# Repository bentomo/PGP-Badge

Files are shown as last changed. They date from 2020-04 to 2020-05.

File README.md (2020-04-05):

# Pokemon Go Plus Custom Badge

## Installing Toolchain

This was all tested under Windows 10

1. Install Python 2.7 (This is tested by 2.7.12)
	This is required for the edf-sdk installer

2. Install CMake for Windows (Tested using 3.17.0)

3. Install espressif SDK (Tested using Windows installer 2.2)
https://docs.espressif.com/projects/esp-idf/en/latest/get-started/#id1

I needed to use this because of an installer problem
https://github.com/espressif/esp-idf/issues/4744

`python.exe -m pip install --upgrade virtualenv==16.7.9`

Then run the program as administrator

## Extracting a MAC, Blob, and Key

Note that this is unusable without a Mac address, BLOB and device key from an **ORIGINAL** Pokemon GO plus
Pokeball plus and Gotcha not supported
https://github.com/Jesus805/Suota-Go-Plus

It's easiest to use the release page app 

Currently the app is bugged, it can download custom firmware but you need to use the  nRF android app to extract the values and restore the FW
MAC address is given by the app
characteristic `870d5ab1-20bd-b88a-5746-a97f5c33ea58` is the device key
characteristic `fe0002af-f8e3-f1b2-b141-b40adf381d18` is the blob

To restore the FW

1. Write 0x01 to Characteristic `6b64be6f-5467-d8b5-7143-1716be1b96be`
2. Disconnect from the device
3. Wait a few seconds
4. Press the Pokemon Go Plus button, it should be flashing blue or white

## Building the firmware

1. Open a command window
2. Browse to the esp-idf folder and run export.bat to setup sdk
3. Browse to the pgpemu-esp32 project folder and run `idf.py menuconfig`
4. Exit using the default configuration
5. Modify your secrets.c file with your MAC, Blob, and Key extracted from an original Pokemon GO Plus - This file is not tracked by git
6. Build the firmware using `idf.py build`
7. Flash the firmware using `idf.py -p (PORT) flash` where (PORT) is the COMX that the esp32 enumerated as

For more background read:
http://tinyhack.com/2018/11/21/reverse-engineering-pokemon-go-plus/

## Preliminary parts list
> ESP32 - Bluetooth - https://www.digikey.com/product-detail/en/espressif-systems/ESP32-WROOM-32/1904-1010-1-ND/8544305
> SSD1306 - OLED LCD - https://www.amazon.com/WINGONEER-Display-SSD1306-Headers-Arduino/dp/B07QB65CPS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
> ~~ adafruit 1578 - 500mah battery - https://www.digikey.com/product-detail/en/adafruit-industries-llc/1578/1528-1841-ND/5054539 ~~
> battery - https://www.digikey.com/product-detail/en/tinycircuits/ASR00008/1832-1044-ND/8680974
> BQ27426 - Fuel Gauge - https://www.digikey.com/product-detail/en/texas-instruments/BQ27426YZFR/296-43359-1-ND/5806500
> LM3658 - Battery Charger - https://www.digikey.com/product-detail/en/texas-instruments/LM3658SD-NOPB/LM3658SD-NOPBCT-ND/808013
> TPS63030 - Voltage Regulator - https://www.digikey.com/product-detail/en/texas-instruments/TPS63030DSKR/296-39460-1-ND/5143408
> CP2102N - USB Interface - https://www.digikey.com/product-detail/en/silicon-labs/CP2102N-A01-GQFN20R/336-4826-1-ND/8619802
> USB4085 - Through hole usb c - https://www.digikey.com/product-detail/en/gct/USB4085-GF-A/2073-USB4085-GF-ACT-ND/9859733
> 316040004 - Vibration Motor - https://www.digikey.com/product-detail/en/seeed-technology-co-ltd/316040004/1597-1245-ND/5487673
> ~~ BQ297X - Protection Circuit - http://www.ti.com/lit/ds/symlink/bq2971.pdf ~ Battery includes protection circuit~

Other components not listed
jelly beans
sense resitors
tactile switches
mechanicals

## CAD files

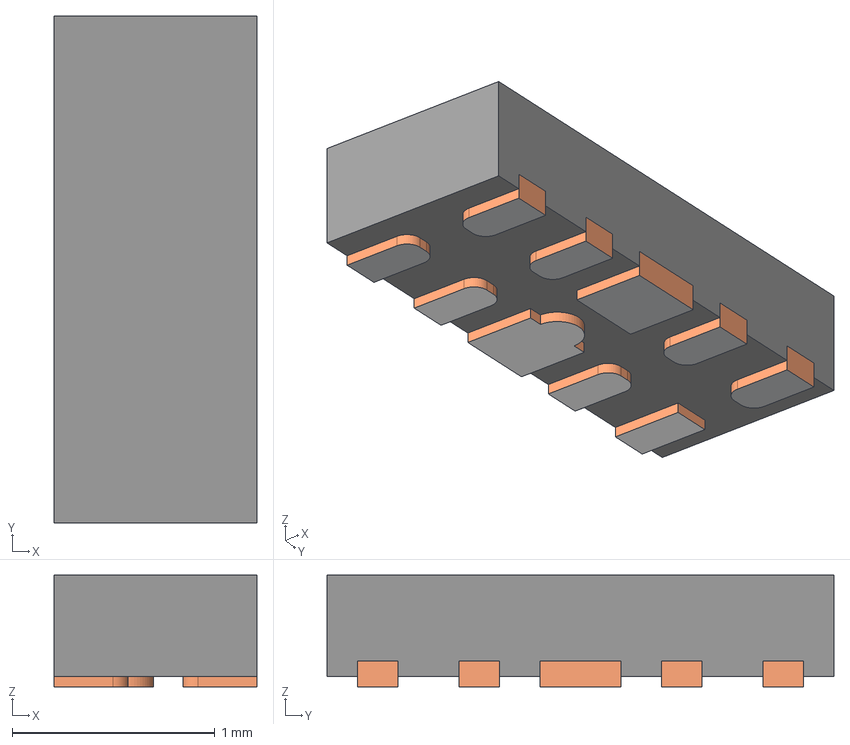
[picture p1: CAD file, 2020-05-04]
pcb/pgpbadge/3dModels/DQA0010A.stp
1.00 x 2.50 x 0.55 mm
BODY-SON
FRAME-DQA0010A
PIN1-ID

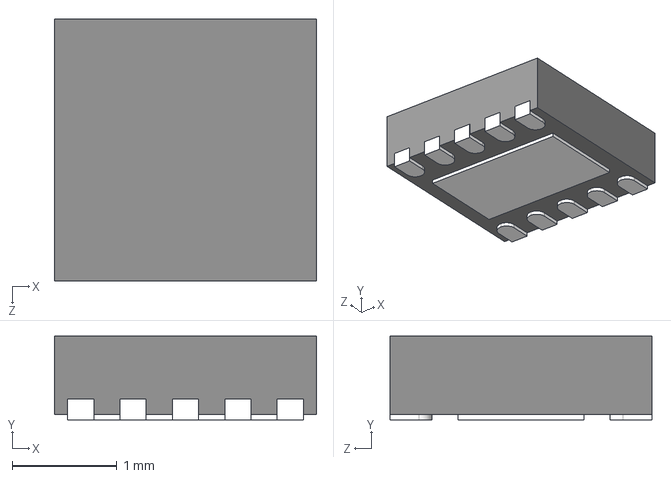
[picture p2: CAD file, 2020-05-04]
pcb/pgpbadge/3dModels/wson-10-ep-2_5_2_5.step
2.50 x 0.8 x 2.50 mm

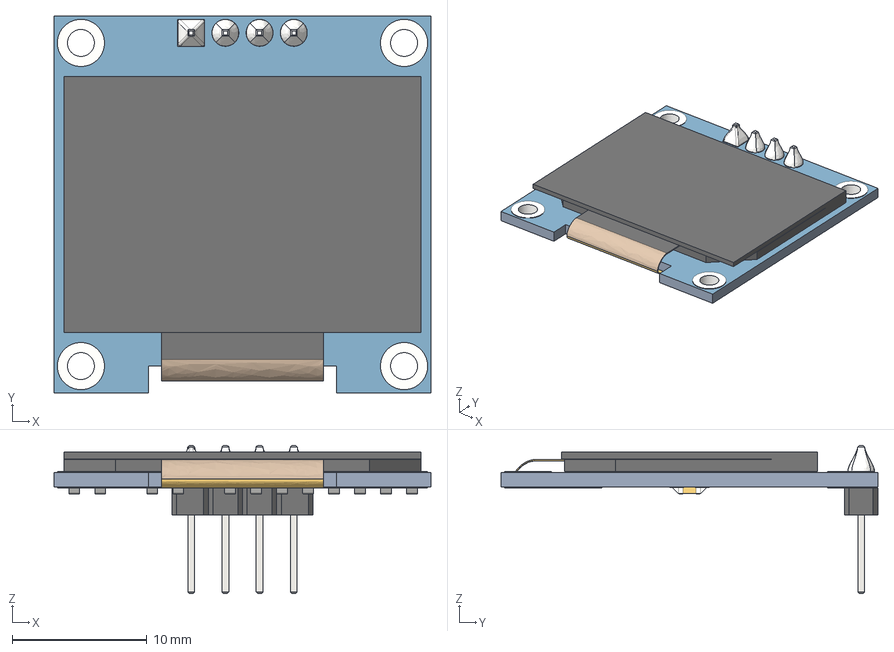
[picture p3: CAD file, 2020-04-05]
pcb/pgpbadge/3dModels/0_96_OLEDv3.step
28.0 x 28.0 x 11.0 mm

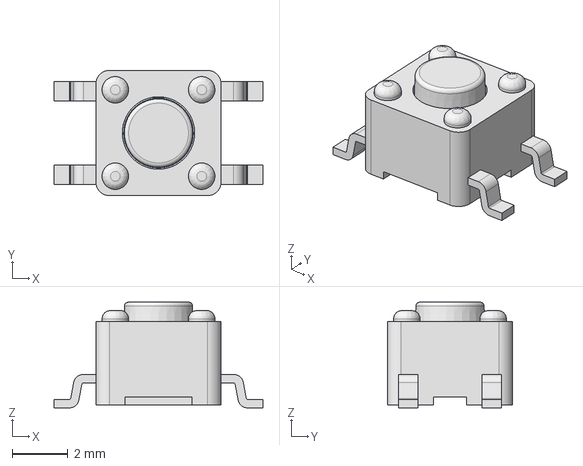
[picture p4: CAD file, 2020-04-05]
pcb/pgpbadge/3dModels/TL3305AFxxxxG.stp
7.50 x 4.50 x 3.80 mm

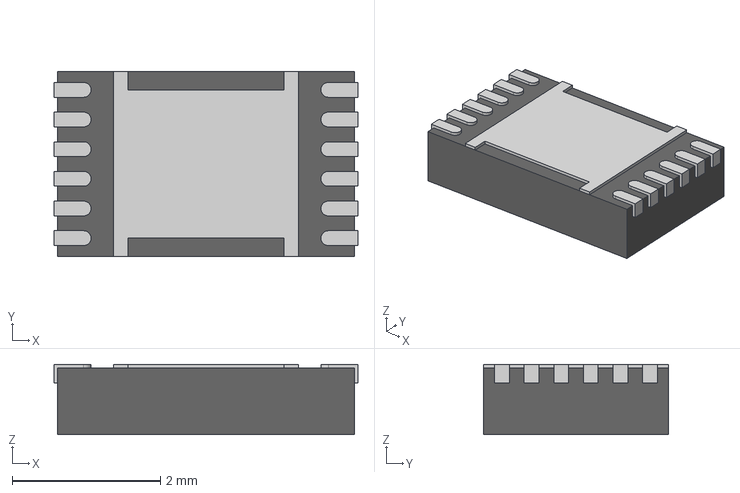
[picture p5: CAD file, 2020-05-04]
pcb/pgpbadge/3dModels/BQ27441DRZT-G1A--3DModel-STEP-191390.STEP
4.10 x 2.50 x 0.95 mm

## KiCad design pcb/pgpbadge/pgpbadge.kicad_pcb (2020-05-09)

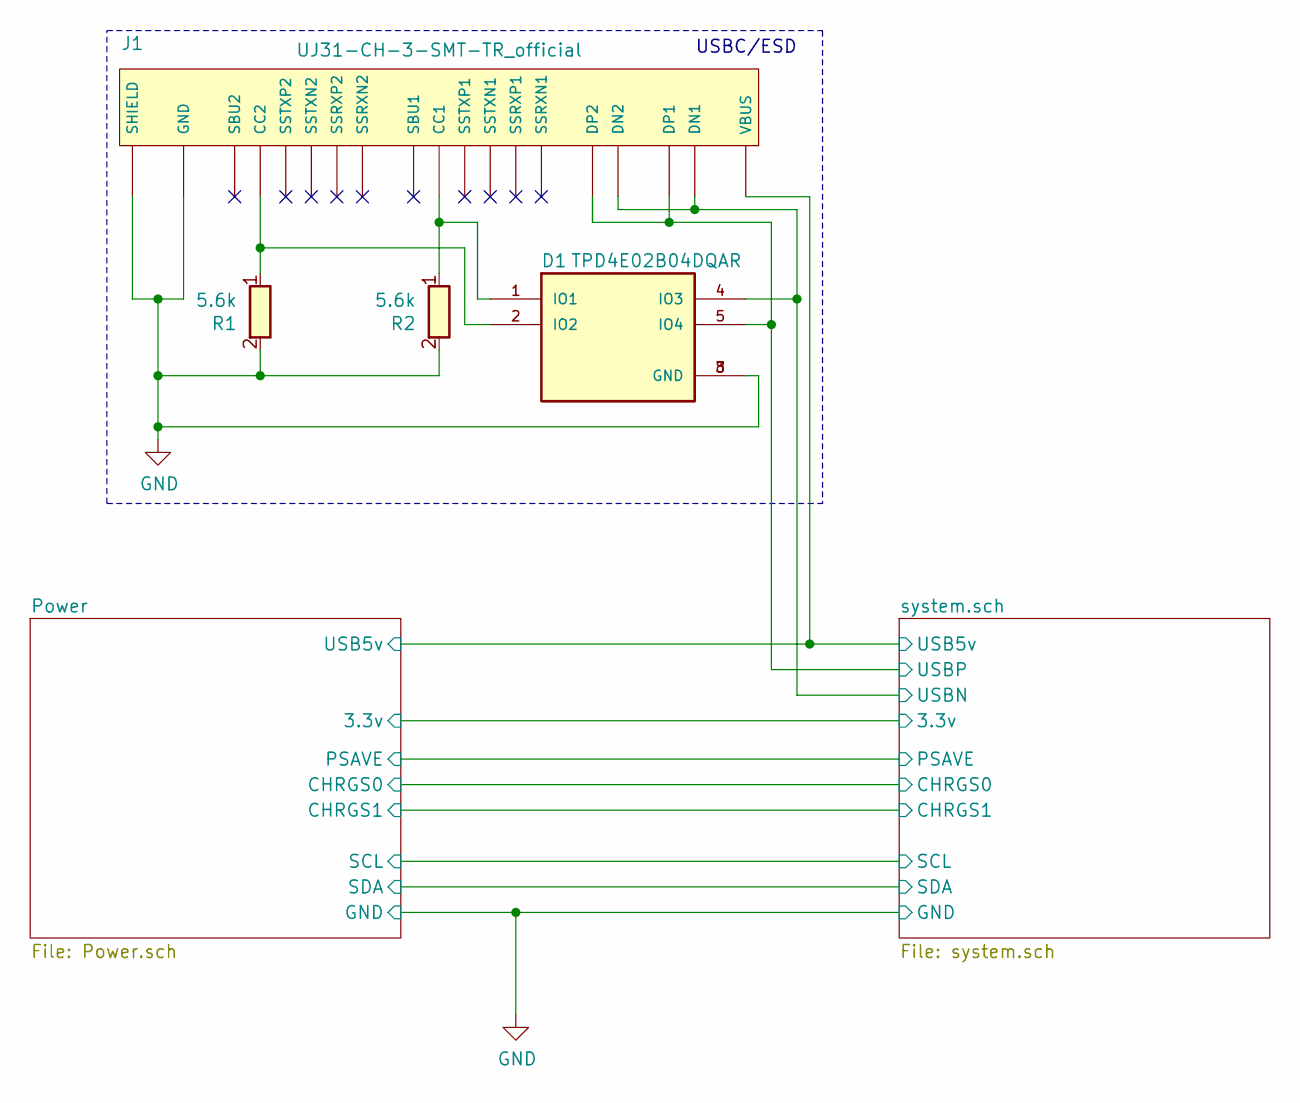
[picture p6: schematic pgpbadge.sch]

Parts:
D1: TPD4E02B04DQAR; DIO_TPD4E02B04DQAR
J1: UJ31-CH-3-SMT-TR_official; CUI_UJ31-CH-3-SMT-TR
R1, R2: 5.6k; R_0402_1005Metric

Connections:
/Power/USB5v: J1.A4 (VBUS), J1.A9 (VBUS), J1.B4 (VBUS), J1.B9 (VBUS); also elsewhere on the board
/system.sch/USBN: D1.4 (IO3), J1.A7 (DN1), J1.B7 (DN2); also elsewhere on the board
/system.sch/USBP: D1.5 (IO4), J1.A6 (DP1), J1.B6 (DP2); also elsewhere on the board
GND: D1.3 (GND), D1.8 (GND), J1.0 (SHIELD), J1.A1 (GND), J1.A12 (GND), J1.B1 (GND), J1.B12 (GND), R1.2, R2.2; also elsewhere on the board
unnamed: D1.1 (IO1), J1.A5 (CC1), R2.1
unnamed: D1.2 (IO2), J1.B5 (CC2), R1.1

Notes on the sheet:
USBC/ESD

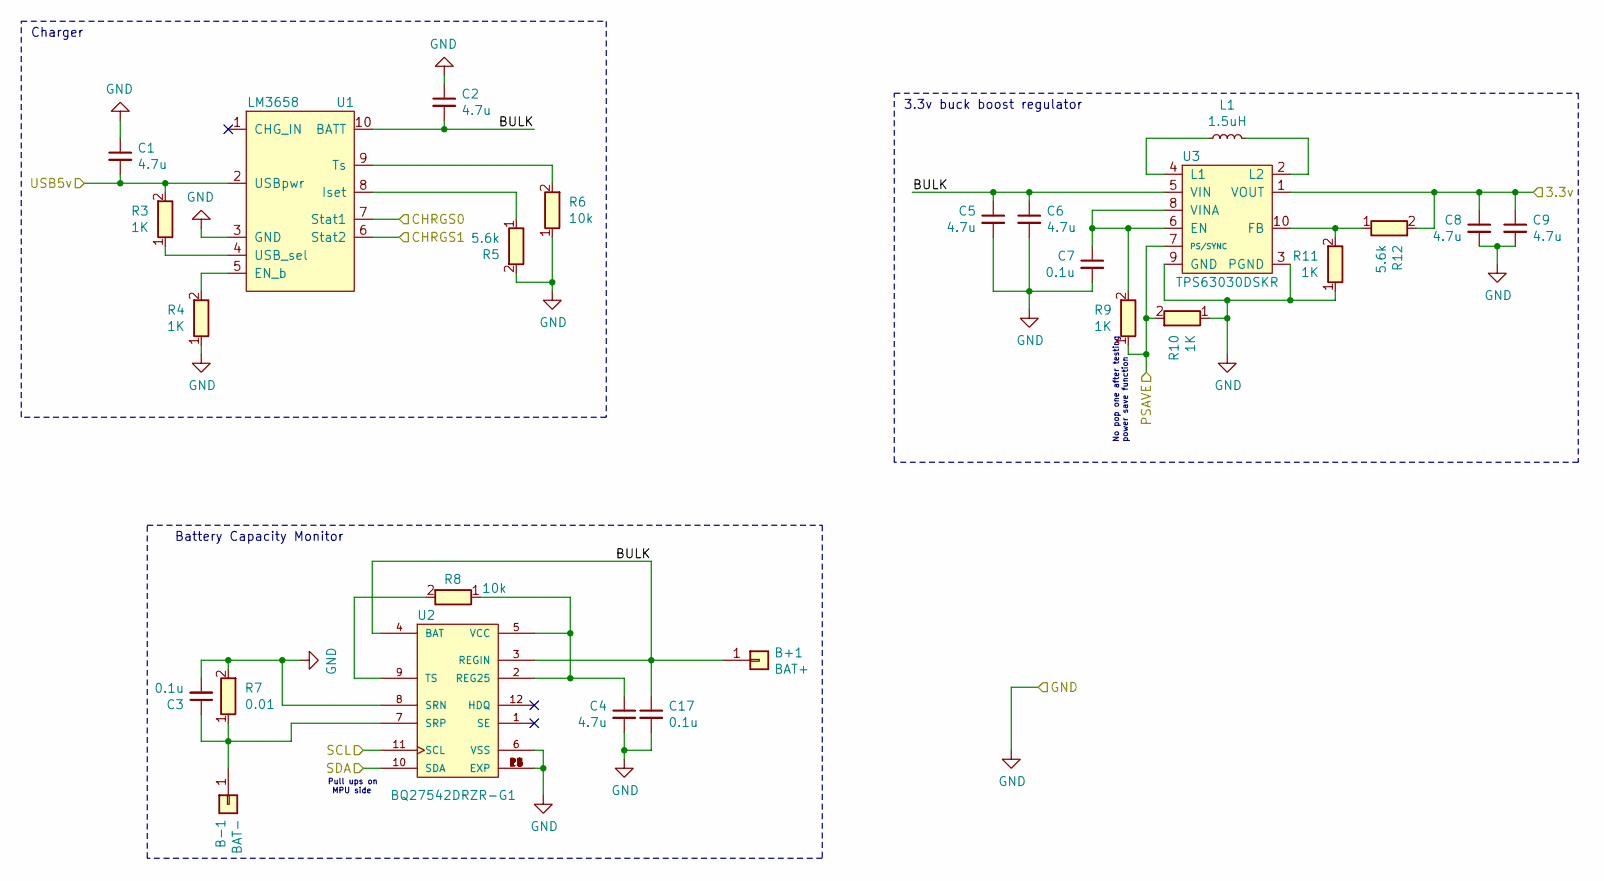
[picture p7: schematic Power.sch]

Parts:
B+1: BAT+; solder_pad
B-1: BAT-; solder_pad
C1, C2, C4, C5, C6, C8, C9: 4.7u; C_0805_2012Metric
C3, C7, C17: 0.1u; C_0402_1005Metric
L1: 1.5uH; L_1008_2520Metric
R3, R4, R9, R10, R11: 1K; R_0402_1005Metric
R5, R12: 5.6k; R_0402_1005Metric
R6, R8: 10k; R_0402_1005Metric
R7: 0.01; R_1206_3216Metric
U1: LM3658; wson-10-3x3
U2: BQ27542DRZR-G1; SON40P250X400X100-13N
U3: TPS63030DSKR; 10-WFDFN_EP_2.5_2.5

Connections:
/Power/BULK: B+1.1, C2.2, C5.1, C6.1, C17.1, U1.10 (BATT), U2.3 (REGIN), U2.4 (BAT), U3.5 (VIN)
/Power/CHRGS0: U1.7 (Stat1); also elsewhere on the board
/Power/CHRGS1: U1.6 (Stat2); also elsewhere on the board
/Power/PSAVE: R9.1, R10.2, U3.7 (PS/SYNC); also elsewhere on the board
/Power/SCL: U2.11 (SCL); also elsewhere on the board
/Power/SDA: U2.10 (SDA); also elsewhere on the board
/Power/USB5v: C1.2, R3.2, U1.2 (USBpwr); also elsewhere on the board
GND: C1.1, C2.1, C3.2, C4.2, C5.2, C6.2, C7.2, C8.2, C9.2, C17.2, R4.1, R5.2, R6.1, R7.2, R10.1, R11.1, U1.3 (GND), U2.6 (VSS), U2.8 (SRN), U2.13 (EXP), U2.14 (EXP), U2.15 (EXP), U2.P1 (EXP), U2.P2 (EXP), U2.P3 (EXP), U2.P4 (EXP), U2.P5 (EXP), U2.P6 (EXP), U3.3 (PGND), U3.9 (GND); also elsewhere on the board
unnamed: B-1.1, C3.1, R7.1, U2.7 (SRP)
unnamed: C4.1, R8.1, U2.2 (REG25), U2.5 (VCC)
unnamed: C7.1, R9.2, U3.6 (EN), U3.8 (VINA)
unnamed: L1.1, U3.4 (L1)
unnamed: L1.2, U3.2 (L2)
unnamed: R3.1, U1.4 (USB_sel)
unnamed: R4.2, U1.5 (EN_b)
unnamed: R5.1, U1.8 (Iset)
unnamed: R6.2, U1.9 (Ts)
unnamed: R8.2, U2.9 (TS)
unnamed: R11.2, R12.1, U3.10 (FB)

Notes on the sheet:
Pull ups on MPU side
No pop one after testing power save function
3.3v buck boost regulator
Battery Capacity Monitor
Charger

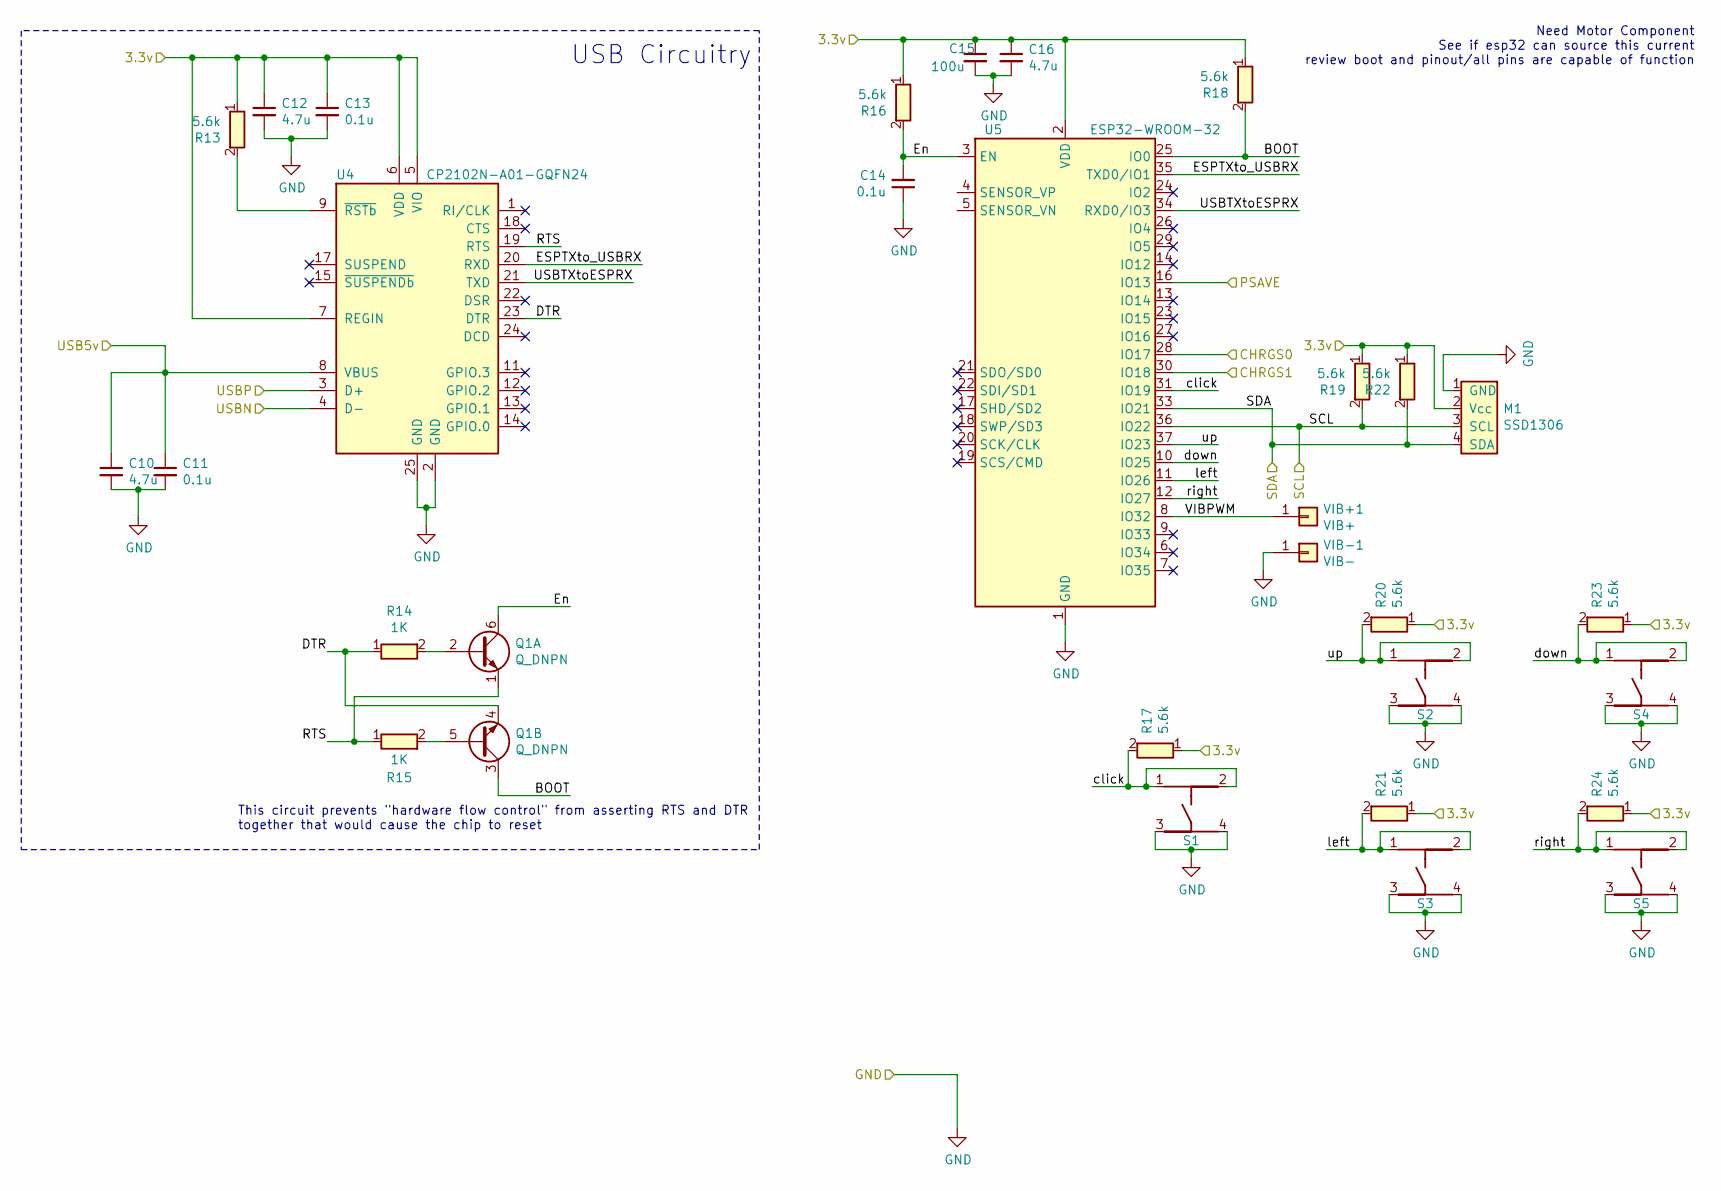
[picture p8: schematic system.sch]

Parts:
C10, C12, C16: 4.7u; C_0805_2012Metric
C11, C13, C14: 0.1u; C_0402_1005Metric
C15: 100u; C_1206_3216Metric
M1: SSD1306; ssd1306
Q1: Q_DNPN; SOT-363_SC-70-6
R13, R16, R17, R18, R19, R20, R21, R22, R23, R24: 5.6k; R_0402_1005Metric
R14, R15: 1K; R_0402_1005Metric
S1, S2, S3, S4, S5: tactile_TL3305AF160QG
U4: CP2102N-A01-GQFN24; QFN-24-1EP_4x4mm_P0.5mm_EP2.6x2.6mm
U5: ESP32-WROOM-32
VIB+1: VIB+; solder_pad
VIB-1: VIB-; solder_pad

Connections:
/Power/CHRGS0: U5.28 (IO17); also elsewhere on the board
/Power/CHRGS1: U5.30 (IO18); also elsewhere on the board
/Power/PSAVE: U5.16 (IO13); also elsewhere on the board
/Power/SCL: M1.3 (SCL), R19.2, U5.36 (IO22); also elsewhere on the board
/Power/SDA: M1.4 (SDA), R22.2, U5.33 (IO21); also elsewhere on the board
/Power/USB5v: C10.1, C11.1, U4.8 (VBUS); also elsewhere on the board
/system.sch/BOOT: Q1.3 (C2), R18.2, U5.25 (IO0)
/system.sch/DTR: Q1.4 (E2), R14.1, U4.23 (DTR)
/system.sch/ESPTXto_USBRX: U4.20 (RXD), U5.35 (TXD0/IO1)
/system.sch/En: C14.2, Q1.6 (C1), R16.2, U5.3 (EN)
/system.sch/RTS: Q1.1 (E1), R15.1, U4.19 (RTS)
/system.sch/USBN: U4.4 (D-); also elsewhere on the board
/system.sch/USBP: U4.3 (D+); also elsewhere on the board
/system.sch/USBTXtoESPRX: U4.21 (TXD), U5.34 (RXD0/IO3)
/system.sch/VIBPWM: U5.8 (IO32), VIB+1.1
/system.sch/click: R17.2, S1.1, S1.2, U5.31 (IO19)
/system.sch/down: R23.2, S4.1, S4.2, U5.10 (IO25)
/system.sch/left: R21.2, S3.1, S3.2, U5.11 (IO26)
/system.sch/right: R24.2, S5.1, S5.2, U5.12 (IO27)
/system.sch/up: R20.2, S2.1, S2.2, U5.37 (IO23)
GND: C10.2, C11.2, C12.2, C13.2, C14.1, C15.2, C16.2, M1.1 (GND), S1.3, S1.4, S2.3, S2.4, S3.3, S3.4, S4.3, S4.4, S5.3, S5.4, U4.2 (GND), U4.25 (GND), U5.1 (GND), U5.15 (GND), U5.38 (GND), U5.39 (GND), VIB-1.1; also elsewhere on the board
unnamed: Q1.2 (B1), R14.2
unnamed: Q1.5 (B2), R15.2

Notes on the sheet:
This circuit prevents "hardware flow control" from asserting RTS and DTR together that would cause the chip to reset
USB Circuitry
Need Motor Component See if esp32 can source this current review boot and pinout/all pins are capable of function

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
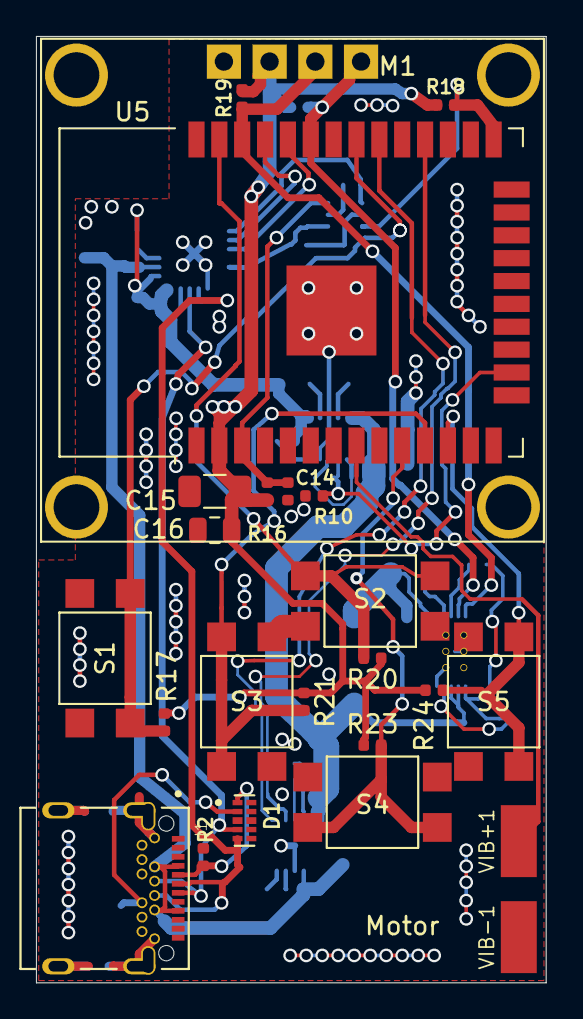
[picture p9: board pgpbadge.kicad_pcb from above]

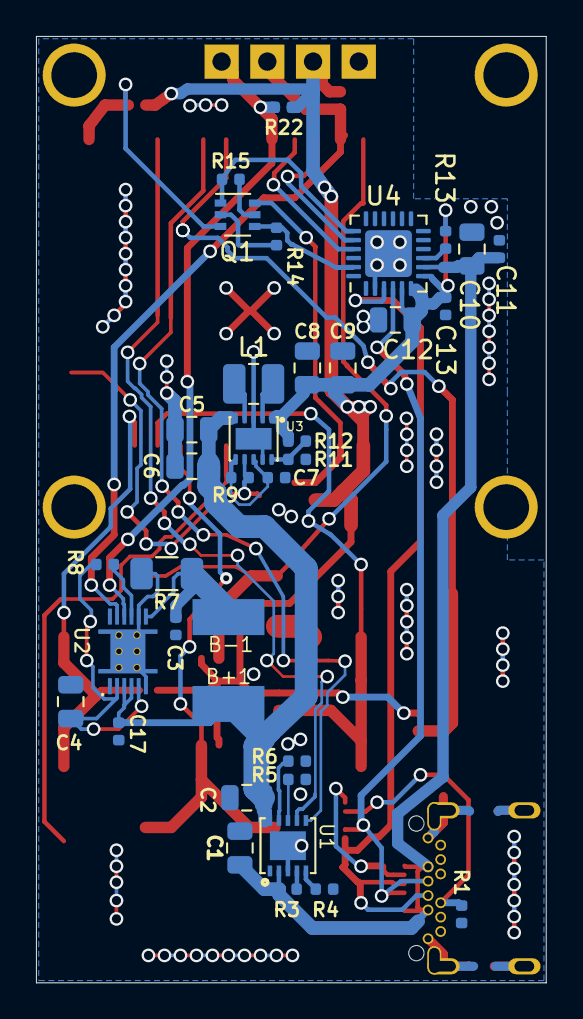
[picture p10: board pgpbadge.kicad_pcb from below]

Board: 4 copper layers, 28.3 x 52.6 mm, 60 parts (36 on the bottom side), 39 nets.

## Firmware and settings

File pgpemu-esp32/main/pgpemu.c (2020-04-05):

#include "freertos/FreeRTOS.h"
#include "freertos/task.h"
#include "freertos/event_groups.h"
#include "freertos/queue.h"
#include "driver/uart.h"
#include "esp32/aes.h"

#define EX_UART_NUM UART_NUM_0


#include "esp_system.h"
#include "esp_log.h"
#include "nvs_flash.h"
#include "esp_bt.h"

#include "esp_gap_ble_api.h"
#include "esp_gatts_api.h"
#include "esp_bt_main.h"
#include "pgpemu.h"
#include "pgp-cert.h"
#include "secrets.h"
#include "esp_gatt_common_api.h"

#define GATTS_TABLE_TAG "PGPEMU"

#define PROFILE_NUM                 1
#define PROFILE_APP_IDX             0
#define ESP_APP_ID                  0x55
#define PGP_DEVICE_NAME          "Pokemon GO Plus"
//#define PGP_DEVICE_NAME          "Pokemon PBP"
/* #define SVC_INST_ID                 0 */
/* #define BATTERY_INST_ID                 1 */
/* #define LED_BUTTON_INST_ID                 2 */


#define BATTERY_INST_ID                 0
#define LED_BUTTON_INST_ID              1
#define CERT_INST_ID              2


/* The max length of characteristic value. When the gatt client write or prepare write,
*  the data length must be less than MAX_VALUE_LENGTH.
*/
#define MAX_VALUE_LENGTH 500
#define PREPARE_BUF_MAX_SIZE        1024
#define CHAR_DECLARATION_SIZE       (sizeof(uint8_t))

#define ADV_CONFIG_FLAG             (1 << 0)
#define SCAN_RSP_CONFIG_FLAG        (1 << 1)

static uint8_t adv_config_done       = 0;


uint16_t battery_handle_table[BATTERY_LAST_IDX];
uint16_t led_button_handle_table[LED_BUTTON_LAST_IDX];
uint16_t certificate_handle_table[CERT_LAST_IDX];

uint16_t last_conn_id  = 0;
esp_gatt_if_t last_if = 0;

//in ESP32, bt_mac is base_mac + 2
uint8_t mac[6];
uint8_t bt_mac[6];

//uint8_t mac[] = {0x98, 0xB6, 0xE9, 0x13, 0xB5, 0x91};
//uint8_t bt_mac[] = {0x98, 0xB6, 0xE9, 0x13, 0xB5, 0x93};


uint8_t session_key[16];
int cert_state = 0;


typedef struct {
	uint16_t handle;
    uint8_t                 *prepare_buf;
    int                     prepare_len;
} prepare_type_env_t;

static QueueHandle_t button_queue;

static prepare_type_env_t prepare_write_env;

static uint8_t raw_adv_data[] = {
        /* flags */
        0x02, 0x01, 0x06,
        /* device name */
	0x10, 0x09, 'P', 'o', 'k', 'e', 'm', 'o', 'n', ' ', 'G', 'O', ' ','P', 'l', 'u','s',
        //0x0c, 0x09, 'P', 'o', 'k', 'e', 'm', 'o', 'n', ' ', 'P', 'B', 'P',
	0x06, 0x20, 0x62, 0x04, 0xC5, 0x21, 0x00
};
static uint8_t raw_scan_rsp_data[] = {
        /* flags */
        0x02, 0x01, 0x06,
        /* tx power */
        0x02, 0x0a, 0xeb,
        /* service uuid */
        0x03, 0x03, 0xFF,0x00
};


static esp_ble_adv_params_t adv_params = {
    .adv_int_min         = 0x20,
    .adv_int_max         = 0x40,
    .adv_type            = ADV_TYPE_IND,
    .own_addr_type       = BLE_ADDR_TYPE_PUBLIC,
    .channel_map         = ADV_CHNL_ALL,
    .adv_filter_policy   = ADV_FILTER_ALLOW_SCAN_ANY_CON_ANY,
};

struct gatts_profile_inst {
    esp_gatts_cb_t gatts_cb;
    uint16_t gatts_if;
    uint16_t app_id;
    uint16_t conn_id;
    uint16_t service_handle;
    esp_gatt_srvc_id_t service_id;
    uint16_t char_handle;
    esp_bt_uuid_t char_uuid;
    esp_gatt_perm_t perm;
    esp_gatt_char_prop_t property;
    uint16_t descr_handle;
    esp_bt_uuid_t descr_uuid;
};

static void gatts_profile_event_handler(esp_gatts_cb_event_t event,
					esp_gatt_if_t gatts_if, esp_ble_gatts_cb_param_t *param);

/* One gatt-based profile one app_id and one gatts_if, this array will store the gatts_if returned by ESP_GATTS_REG_EVT */
static struct gatts_profile_inst pgp_profile_tab[PROFILE_NUM] = {
    [PROFILE_APP_IDX] = {
        .gatts_cb = gatts_profile_event_handler,
        .gatts_if = ESP_GATT_IF_NONE,       /* Not get the gatt_if, so initial is ESP_GATT_IF_NONE */
    },
};

/* Service */
static const uint16_t primary_service_uuid         = ESP_GATT_UUID_PRI_SERVICE;
static const uint16_t character_declaration_uuid   = ESP_GATT_UUID_CHAR_DECLARE;
static const uint16_t character_client_config_uuid = ESP_GATT_UUID_CHAR_CLIENT_CONFIG;
static const uint8_t char_prop_read                =  ESP_GATT_CHAR_PROP_BIT_READ;
static const uint8_t char_prop_write               = ESP_GATT_CHAR_PROP_BIT_WRITE;
static const uint8_t char_prop_read_notify   = ESP_GATT_CHAR_PROP_BIT_READ | ESP_GATT_CHAR_PROP_BIT_NOTIFY;
static const uint8_t char_prop_notify   = ESP_GATT_CHAR_PROP_BIT_NOTIFY;
static const uint8_t dummy_value[2]      = {0x00, 0x00};
static uint8_t cert_buffer[378];


static const uint16_t GATTS_SERVICE_UUID_BATTERY      = 0x180f;
static const uint16_t GATTS_CHAR_UUID_BATTERY_LEVEL = 0x2a19;
static const uint8_t battery_char_value[1]                 = {0x60};


static uint8_t reconnect_challenge[32];
static int has_reconnect_key = 0;

static const esp_gatts_attr_db_t gatt_db_battery[BATTERY_LAST_IDX] = {

    // Service Declaration
    [IDX_BATTERY_SVC]        =
    {{ESP_GATT_AUTO_RSP}, {ESP_UUID_LEN_16, (uint8_t *)&primary_service_uuid, ESP_GATT_PERM_READ,
      sizeof(uint16_t), sizeof(GATTS_SERVICE_UUID_BATTERY), (uint8_t *)&GATTS_SERVICE_UUID_BATTERY}},

    /* Characteristic Declaration */
    [IDX_CHAR_BATTERY_LEVEL]     =
    {{ESP_GATT_AUTO_RSP}, {ESP_UUID_LEN_16, (uint8_t *)&character_declaration_uuid, ESP_GATT_PERM_READ,
      CHAR_DECLARATION_SIZE, CHAR_DECLARATION_SIZE, (uint8_t *)&char_prop_read_notify}},
    /* Characteristic Value */
    [IDX_CHAR_BATTERY_LEVEL_VAL] =
    {{ESP_GATT_AUTO_RSP}, {ESP_UUID_LEN_16, (uint8_t *)&GATTS_CHAR_UUID_BATTERY_LEVEL, ESP_GATT_PERM_READ,
      MAX_VALUE_LENGTH, sizeof(battery_char_value), (uint8_t *)battery_char_value}},

    /* Client Characteristic Configuration Descriptor */
    [IDX_CHAR_BATTERY_LEVEL_CFG]  =
    {{ESP_GATT_AUTO_RSP}, {ESP_UUID_LEN_16, (uint8_t *)&character_client_config_uuid, ESP_GATT_PERM_READ|ESP_GATT_PERM_WRITE,
      sizeof(uint16_t), sizeof(dummy_value), (uint8_t *)dummy_value}},
};



//uuid in reversed order
uint8_t GATTS_SERVICE_UUID_LED_BUTTON[ESP_UUID_LEN_128] = {0xeb, 0x9a, 0x93, 0xb9, 0xb5, 0x82, 0x4c, 0x5c, 0xa3, 0x63, 0xcb, 0x67, 0x62, 0x4, 0xc5, 0x21};
uint8_t GATTS_CHAR_UUID_LED[ESP_UUID_LEN_128] = {0xec, 0x9a, 0x93, 0xb9, 0xb5, 0x82, 0x4c, 0x5c, 0xa3, 0x63, 0xcb, 0x67, 0x62, 0x4, 0xc5, 0x21};
uint8_t GATTS_CHAR_UUID_BUTTON[ESP_UUID_LEN_128] = {0xed, 0x9a, 0x93, 0xb9, 0xb5, 0x82, 0x4c, 0x5c, 0xa3, 0x63, 0xcb, 0x67, 0x62, 0x4, 0xc5, 0x21};
uint8_t GATTS_CHAR_UUID_UNKNOWN[ESP_UUID_LEN_128] = {0xee, 0x9a, 0x93, 0xb9, 0xb5, 0x82, 0x4c, 0x5c, 0xa3, 0x63, 0xcb, 0x67, 0x62, 0x4, 0xc5, 0x21};
uint8_t GATTS_CHAR_UUID_UPDATE_REQUEST[ESP_UUID_LEN_128] = {0xef, 0x9a, 0x93, 0xb9, 0xb5, 0x82, 0x4c, 0x5c, 0xa3, 0x63, 0xcb, 0x67, 0x62, 0x4, 0xc5, 0x21};
uint8_t GATTS_CHAR_UUID_FW_VERSION[ESP_UUID_LEN_128] = {0xf0, 0x9a, 0x93, 0xb9, 0xb5, 0x82, 0x4c, 0x5c, 0xa3, 0x63, 0xcb, 0x67, 0x62, 0x4, 0xc5, 0x21};

static const uint8_t led_char_value[100];

static const uint8_t button_value[2];

uint8_t GATTS_SERVICE_UUID_CERTIFICATE[ESP_UUID_LEN_128] = {0x37, 0x8e, 0xd, 0xef, 0x8e, 0x8b, 0x7f, 0xab, 0x33, 0x44, 0x89, 0x5b, 0x9, 0x77, 0xe8, 0xbb};
uint8_t GATTS_CHAR_UUID_CENTRAL_TO_SFIDA[ESP_UUID_LEN_128] =  {0x38, 0x8e, 0xd, 0xef, 0x8e, 0x8b, 0x7f, 0xab, 0x33, 0x44, 0x89, 0x5b, 0x9, 0x77, 0xe8, 0xbb};
uint8_t GATTS_CHAR_UUID_SFIDA_COMMANDS[ESP_UUID_LEN_128] =  {0x39, 0x8e, 0xd, 0xef, 0x8e, 0x8b, 0x7f, 0xab, 0x33, 0x44, 0x89, 0x5b, 0x9, 0x77, 0xe8, 0xbb};
uint8_t GATTS_CHAR_UUID_SFIDA_TO_CENTRAL[ESP_UUID_LEN_128] =  {0x3a, 0x8e, 0xd, 0xef, 0x8e, 0x8b, 0x7f, 0xab, 0x33, 0x44, 0x89, 0x5b, 0x9, 0x77, 0xe8, 0xbb};
/*
  {ESP_GATT_AUTO_RSP/ESP_GATT_RSP_BY_APP},
  {uuid_length, uuid_val, attribute permission, max length of element, current length of element, element value array}
*/

static const esp_gatts_attr_db_t gatt_db_led_button[LED_BUTTON_LAST_IDX] = {
    // Service Declaration
    [IDX_LED_BUTTON_SVC]        =
    {{ESP_GATT_AUTO_RSP}, {ESP_UUID_LEN_16, (uint8_t *)&primary_service_uuid, ESP_GATT_PERM_READ,
       ESP_UUID_LEN_128, ESP_UUID_LEN_128, (uint8_t *)&GATTS_SERVICE_UUID_LED_BUTTON}},

    /* Characteristic Declaration */
    [IDX_CHAR_LED]     =
    {{ESP_GATT_AUTO_RSP}, {ESP_UUID_LEN_16, (uint8_t *)&character_declaration_uuid, ESP_GATT_PERM_READ,
      CHAR_DECLARATION_SIZE, CHAR_DECLARATION_SIZE, (uint8_t *)&char_prop_write}},
    [IDX_CHAR_LED_VAL] =
    {{ESP_GATT_AUTO_RSP}, {ESP_UUID_LEN_128, (uint8_t *)&GATTS_CHAR_UUID_LED, ESP_GATT_PERM_READ|ESP_GATT_PERM_WRITE,
      MAX_VALUE_LENGTH, sizeof(led_char_value), (uint8_t *)led_char_value}},


    [IDX_CHAR_BUTTON]     =
    {{ESP_GATT_AUTO_RSP}, {ESP_UUID_LEN_16, (uint8_t *)&character_declaration_uuid, ESP_GATT_PERM_READ,
      CHAR_DECLARATION_SIZE, CHAR_DECLARATION_SIZE, (uint8_t *)&char_prop_notify}},
    [IDX_CHAR_BUTTON_VAL] =
    {{ESP_GATT_AUTO_RSP}, {ESP_UUID_LEN_128, (uint8_t *)&GATTS_CHAR_UUID_BUTTON, ESP_GATT_PERM_READ,
      MAX_VALUE_LENGTH, sizeof(button_value), (uint8_t *)button_value}},

    /* Client Characteristic Configuration Descriptor */
    [IDX_CHAR_BUTTON_CFG]  =
    {{ESP_GATT_AUTO_RSP}, {ESP_UUID_LEN_16, (uint8_t *)&character_client_config_uuid, ESP_GATT_PERM_READ | ESP_GATT_PERM_WRITE,
      sizeof(uint16_t), sizeof(dummy_value), (uint8_t *)dummy_value}},

    /* Characteristic Declaration */
    [IDX_CHAR_UNKNOWN]     =
    {{ESP_GATT_AUTO_RSP}, {ESP_UUID_LEN_16, (uint8_t *)&character_declaration_uuid, ESP_GATT_PERM_READ,
      CHAR_DECLARATION_SIZE, CHAR_DECLARATION_SIZE, (uint8_t *)&char_prop_write}},
    [IDX_CHAR_UNKNOWN_VAL] =
    {{ESP_GATT_AUTO_RSP}, {ESP_UUID_LEN_128, (uint8_t *)&GATTS_CHAR_UUID_UNKNOWN, ESP_GATT_PERM_READ,
      MAX_VALUE_LENGTH, sizeof(led_char_value), (uint8_t *)led_char_value}},

    /* Characteristic Declaration */
    [IDX_CHAR_UPDATE_REQUEST]     =
    {{ESP_GATT_AUTO_RSP}, {ESP_UUID_LEN_16, (uint8_t *)&character_declaration_uuid, ESP_GATT_PERM_READ,
      CHAR_DECLARATION_SIZE, CHAR_DECLARATION_SIZE, (uint8_t *)&char_prop_write}},
    [IDX_CHAR_UPDATE_REQUEST_VAL] =
    {{ESP_GATT_AUTO_RSP}, {ESP_UUID_LEN_128, (uint8_t *)&GATTS_CHAR_UUID_UPDATE_REQUEST, ESP_GATT_PERM_READ,
      MAX_VALUE_LENGTH, sizeof(led_char_value), (uint8_t *)led_char_value}},

    /* Characteristic Declaration */
    [IDX_CHAR_FW_VERSION]     =
    {{ESP_GATT_AUTO_RSP}, {ESP_UUID_LEN_16, (uint8_t *)&character_declaration_uuid, ESP_GATT_PERM_READ,
      CHAR_DECLARATION_SIZE, CHAR_DECLARATION_SIZE, (uint8_t *)&char_prop_read}},
    [IDX_CHAR_FW_VERSION_VAL] =
    {{ESP_GATT_AUTO_RSP}, {ESP_UUID_LEN_128, (uint8_t *)&GATTS_CHAR_UUID_FW_VERSION, ESP_GATT_PERM_READ,
      MAX_VALUE_LENGTH, sizeof(led_char_value), (uint8_t *)led_char_value}},

};


static const esp_gatts_attr_db_t gatt_db_certificate[CERT_LAST_IDX] = {
    // Service Declaration
    [IDX_CERT_SVC]        =
    {{ESP_GATT_AUTO_RSP}, {ESP_UUID_LEN_16, (uint8_t *)&primary_service_uuid, ESP_GATT_PERM_READ,
       ESP_UUID_LEN_128, ESP_UUID_LEN_128, (uint8_t *)&GATTS_SERVICE_UUID_CERTIFICATE}},

    /* Characteristic Declaration */
    [IDX_CHAR_CENTRAL_TO_SFIDA]     =
    {{ESP_GATT_AUTO_RSP}, {ESP_UUID_LEN_16, (uint8_t *)&character_declaration_uuid, ESP_GATT_PERM_READ,
      CHAR_DECLARATION_SIZE, CHAR_DECLARATION_SIZE, (uint8_t *)&char_prop_write}},
    [IDX_CHAR_CENTRAL_TO_SFIDA_VAL] =
    {{ESP_GATT_AUTO_RSP}, {ESP_UUID_LEN_128, (uint8_t *)&GATTS_CHAR_UUID_CENTRAL_TO_SFIDA, ESP_GATT_PERM_READ|ESP_GATT_PERM_WRITE,
      MAX_VALUE_LENGTH, sizeof(led_char_value), (uint8_t *)led_char_value}},


    [IDX_CHAR_SFIDA_COMMANDS]     =
    {{ESP_GATT_AUTO_RSP}, {ESP_UUID_LEN_16, (uint8_t *)&character_declaration_uuid, ESP_GATT_PERM_READ,
      CHAR_DECLARATION_SIZE, CHAR_DECLARATION_SIZE, (uint8_t *)&char_prop_notify}},
    [IDX_CHAR_SFIDA_COMMANDS_VAL] =
    {{ESP_GATT_AUTO_RSP}, {ESP_UUID_LEN_128, (uint8_t *)&GATTS_CHAR_UUID_SFIDA_COMMANDS, ESP_GATT_PERM_READ,
      MAX_VALUE_LENGTH, sizeof(led_char_value), (uint8_t *)led_char_value}},

    /* Client Characteristic Configuration Descriptor */
    [IDX_CHAR_SFIDA_COMMANDS_CFG]  =
    {{ESP_GATT_AUTO_RSP}, {ESP_UUID_LEN_16, (uint8_t *)&character_client_config_uuid, ESP_GATT_PERM_READ | ESP_GATT_PERM_WRITE,
      sizeof(uint16_t), sizeof(dummy_value), (uint8_t *)dummy_value}},

    /* Characteristic Declaration */
    [IDX_CHAR_SFIDA_TO_CENTRAL]     =
    {{ESP_GATT_AUTO_RSP}, {ESP_UUID_LEN_16, (uint8_t *)&character_declaration_uuid, ESP_GATT_PERM_READ,
      CHAR_DECLARATION_SIZE, CHAR_DECLARATION_SIZE, (uint8_t *)&char_prop_read}},
    [IDX_CHAR_SFIDA_TO_CENTRAL_VAL] =
    {{ESP_GATT_AUTO_RSP}, {ESP_UUID_LEN_128, (uint8_t *)&GATTS_CHAR_UUID_SFIDA_TO_CENTRAL, ESP_GATT_PERM_READ,
      MAX_VALUE_LENGTH, sizeof(cert_buffer), (uint8_t *)cert_buffer}},
};

const char *battery_char_names[] =  {
  "BATTERY_SVC",
  "CHAR_BATTERY_LEVEL",
  "CHAR_BATTERY_LEVEL_VAL",
  "CHAR_BATTERY_LEVEL_CFG",
};

const char *led_button_char_names[] =  {
  "LED_BUTTON_SVC",
  "CHAR_LED",
  "CHAR_LED_VAL",
  "CHAR_BUTTON",
  "CHAR_BUTTON_VAL",
  "CHAR_BUTTON_CFG,   "
  "CHAR_UNKNOWN",
  "CHAR_UNKNOWN_VAL",
  "CHAR_UPDATE_REQUEST",
  "CHAR_UPDATE_REQUEST_VAL",
  "CHAR_FW_VERSION",
  "CHAR_FW_VERSION_VAL"
};

const char *cert_char_names[] =  {
  "CERT_SVC",
  "CHAR_CENTRAL_TO_SFIDA",
  "CHAR_CENTRAL_TO_SFIDA_VAL",
  "CHAR_SFIDA_COMMANDS",
  "CHAR_SFIDA_COMMANDS_VAL",
  "CHAR_SFIDA_COMMANDS_CFG",
  "CHAR_SFIDA_TO_CENTRAL",
  "CHAR_SFIDA_TO_CENTRAL_VAL"
};

const char *UNKNOWN_HANDLE_NAME = "<UNKNOWN HANDLE NAME>";

static int find_handle_index(uint16_t handle, uint16_t *handle_table, int count)
{
	for (int i =0; i < count; i++) {
		if (handle_table[i] == handle)
			return i;
	}
	return -1;
}

//for debugging
static const char *char_name_from_handle(uint16_t handle)
{
	int idx;
	idx = find_handle_index(handle, battery_handle_table, BATTERY_LAST_IDX);
	if (idx >= 0)
		return battery_char_names[idx];
	idx = find_handle_index(handle, led_button_handle_table, LED_BUTTON_LAST_IDX);
	if (idx >= 0)
		return led_button_char_names[idx];

	idx = find_handle_index(handle, certificate_handle_table, CERT_LAST_IDX);
	if (idx >= 0)
		return cert_char_names[idx];

	return UNKNOWN_HANDLE_NAME;
}

static void generate_first_challenge()
{
    //fill in cert_buffer
    uint8_t the_challenge[16];
    memset(the_challenge, 0x41, 16);
    uint8_t main_nonce[16];
    memset(main_nonce, 0x42, 16);

    //use fixed key for easier debugging
    memset(session_key, 0x43, 16);
    uint8_t outer_nonce[16];
    memset(outer_nonce, 0x44, 16);
    generate_chal_0(bt_mac, the_challenge, main_nonce, session_key, outer_nonce,
		    (struct challenge_data *)cert_buffer);
}

static void gap_event_handler(esp_gap_ble_cb_event_t event, esp_ble_gap_cb_param_t *param)
{
    switch (event) {
        case ESP_GAP_BLE_ADV_DATA_RAW_SET_COMPLETE_EVT:
            adv_config_done &= (~ADV_CONFIG_FLAG);
            if (adv_config_done == 0){
                esp_ble_gap_start_advertising(&adv_params);
            }
            break;
        case ESP_GAP_BLE_SCAN_RSP_DATA_RAW_SET_COMPLETE_EVT:
            adv_config_done &= (~SCAN_RSP_CONFIG_FLAG);
            if (adv_config_done == 0){
                esp_ble_gap_start_advertising(&adv_params);
            }
            break;
        case ESP_GAP_BLE_ADV_START_COMPLETE_EVT:
            /* advertising start complete event to indicate advertising start successfully or failed */
            if (param->adv_start_cmpl.status != ESP_BT_STATUS_SUCCESS) {
                ESP_LOGE(GATTS_TABLE_TAG, "advertising start failed");
            }else{
                ESP_LOGI(GATTS_TABLE_TAG, "advertising start successfully");
            }
            break;
        case ESP_GAP_BLE_ADV_STOP_COMPLETE_EVT:
            if (param->adv_stop_cmpl.status != ESP_BT_STATUS_SUCCESS) {
                ESP_LOGE(GATTS_TABLE_TAG, "Advertising stop failed");
            }
            else {
                ESP_LOGI(GATTS_TABLE_TAG, "Stop adv successfully\n");
            }
            break;
        case ESP_GAP_BLE_UPDATE_CONN_PARAMS_EVT:
            ESP_LOGI(GATTS_TABLE_TAG, "update connection params status = %d, min_int = %d, max_int = %d,conn_int = %d,latency = %d, timeout = %d",
                  param->update_conn_params.status,
                  param->update_conn_params.min_int,
                  param->update_conn_params.max_int,
                  param->update_conn_params.conn_int,
                  param->update_conn_params.latency,
                  param->update_conn_params.timeout);
            break;
        default:
            break;
    }
}
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
void app_main()
{
    esp_err_t ret;

    /* Initialize NVS. */
    ret = nvs_flash_init();
    if (ret == ESP_ERR_NVS_NO_FREE_PAGES || ret == ESP_ERR_NVS_NEW_VERSION_FOUND) {
        ESP_ERROR_CHECK(nvs_flash_erase());
        ret = nvs_flash_init();
    }
    ESP_ERROR_CHECK( ret );


    /* Configure parameters of an UART driver,
     * communication pins and install the driver */
    uart_config_t uart_config = {
        .baud_rate = 115200,
        .data_bits = UART_DATA_8_BITS,
        .parity = UART_PARITY_DISABLE,
        .stop_bits = UART_STOP_BITS_1,
        .flow_ctrl = UART_HW_FLOWCTRL_DISABLE
    };

    uart_param_config(EX_UART_NUM, &uart_config);

    //Set UART log level
    esp_log_level_set(TAG, ESP_LOG_INFO);
    //Set UART pins (using UART0 default pins ie no changes.)
    uart_set_pin(EX_UART_NUM, UART_PIN_NO_CHANGE, UART_PIN_NO_CHANGE, UART_PIN_NO_CHANGE, UART_PIN_NO_CHANGE);
    //Install UART driver, and get the queue.
    uart_driver_install(EX_UART_NUM, BUF_SIZE * 2, BUF_SIZE * 2, 20, &uart0_queue, 0);

    button_queue = xQueueCreate( 10, sizeof( int ) );

   //Create a task to handler UART event from ISR
    xTaskCreate(uart_event_task, "uart_event_task", 2048, NULL, 12, NULL);

    xTaskCreate(auto_button_task, "auto_button_task", 2048, NULL, 12, NULL);

    ESP_ERROR_CHECK(esp_bt_controller_mem_release(ESP_BT_MODE_CLASSIC_BT));

    memcpy(bt_mac, MAC, 6);
    memcpy(mac, MAC, 6);

    mac[5] -= 2; //TODO: check what happens if last byte is 0 or 1
    
    esp_base_mac_addr_set(mac);

    esp_bt_controller_config_t bt_cfg = BT_CONTROLLER_INIT_CONFIG_DEFAULT();
    ret = esp_bt_controller_init(&bt_cfg);
    if (ret) {
        ESP_LOGE(GATTS_TABLE_TAG, "%s enable controller failed: %s", __func__, esp_err_to_name(ret));
        return;
    }




    esp_log_buffer_hex(GATTS_TABLE_TAG, cert_buffer, sizeof(cert_buffer));
    ret = esp_bt_controller_enable(ESP_BT_MODE_BLE);
    if (ret) {
        ESP_LOGE(GATTS_TABLE_TAG, "%s enable controller failed: %s", __func__, esp_err_to_name(ret));
        return;
    }

    ret = esp_bluedroid_init();
    if (ret) {
        ESP_LOGE(GATTS_TABLE_TAG, "%s init bluetooth failed: %s", __func__, esp_err_to_name(ret));
        return;
    }

    ret = esp_bluedroid_enable();
    if (ret) {
        ESP_LOGE(GATTS_TABLE_TAG, "%s enable bluetooth failed: %s", __func__, esp_err_to_name(ret));
        return;
    }

    ret = esp_ble_gatts_register_callback(gatts_event_handler);
    if (ret){
        ESP_LOGE(GATTS_TABLE_TAG, "gatts register error, error code = %x", ret);
        return;
    }

    ret = esp_ble_gap_register_callback(gap_event_handler);
    if (ret){
        ESP_LOGE(GATTS_TABLE_TAG, "gap register error, error code = %x", ret);
        return;
    }

    ret = esp_ble_gatts_app_register(ESP_APP_ID);
    if (ret){
        ESP_LOGE(GATTS_TABLE_TAG, "gatts app register error, error code = %x", ret);
        return;
    }

    /* set the security iocap & auth_req & key size & init key response key parameters to the stack*/
    esp_ble_auth_req_t auth_req = ESP_LE_AUTH_BOND;     //bonding with peer device after authentication
    esp_ble_io_cap_t iocap = ESP_IO_CAP_NONE;           //set the IO capability to No output No input
    uint8_t key_size = 16;      //the key size should be 7~16 bytes
    uint8_t init_key = ESP_BLE_ENC_KEY_MASK | ESP_BLE_ID_KEY_MASK;
    uint8_t rsp_key = ESP_BLE_ENC_KEY_MASK | ESP_BLE_ID_KEY_MASK;
    esp_ble_gap_set_security_param(ESP_BLE_SM_AUTHEN_REQ_MODE, &auth_req, sizeof(uint8_t));
    esp_ble_gap_set_security_param(ESP_BLE_SM_IOCAP_MODE, &iocap, sizeof(uint8_t));
    esp_ble_gap_set_security_param(ESP_BLE_SM_MAX_KEY_SIZE, &key_size, sizeof(uint8_t));
    /* If your BLE device act as a Slave, the init_key means you hope which types of key of the master should distribut to you,
    and the response key means which key you can distribut to the Master;
    If your BLE device act as a master, the response key means you hope which types of key of the slave should distribut to you,
    and the init key means which key you can distribut to the slave. */
    esp_ble_gap_set_security_param(ESP_BLE_SM_SET_INIT_KEY, &init_key, sizeof(uint8_t));
    esp_ble_gap_set_security_param(ESP_BLE_SM_SET_RSP_KEY, &rsp_key, sizeof(uint8_t));


    esp_err_t local_mtu_ret = esp_ble_gatt_set_local_mtu(500);
    if (local_mtu_ret){
        ESP_LOGE(GATTS_TABLE_TAG, "set local  MTU failed, error code = %x", local_mtu_ret);
    }
}

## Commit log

2020-04-05 Base build working, schematic entry nearing completion
    [0_96_OLEDv3.step, Power.sch, TL3305AFxxxxG.stp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]
2020-05-04 Board layout and routing done, need to fix DRC's, add more ground stitching, clean up silscreen, and review
    [BQ27441DRZT-G1A--3DModel-STEP-191390.STEP, DQA0010A.stp, Power.sch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]
2020-05-07 Fixed DRCs except USB C
    [pgpbadge.kicad_pcb]
2020-05-09 DRC's clean, silscreen updated, 1ks changed to 5.6k
    [pgpbadge.kicad_pcb, pgpbadge.sch, system.sch]
